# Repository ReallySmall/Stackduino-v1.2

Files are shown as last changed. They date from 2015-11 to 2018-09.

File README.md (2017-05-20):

Stackduino v1.2
==========
Please visit the project site for details: https://www.stackduino.net/boards/v1_2

Copyright 2017 Richard Iles

Permission is hereby granted, free of charge, to any person obtaining a copy of this software and associated documentation files (the "Software"), to deal in the Software without restriction, including without limitation the rights to use, copy, modify, merge, publish, distribute, sublicense, and/or sell copies of the Software, and to permit persons to whom the Software is furnished to do so, subject to the following conditions:

The above copyright notice and this permission notice shall be included in all copies or substantial portions of the Software.

THE SOFTWARE IS PROVIDED "AS IS", WITHOUT WARRANTY OF ANY KIND, EXPRESS OR IMPLIED, INCLUDING BUT NOT LIMITED TO THE WARRANTIES OF MERCHANTABILITY, FITNESS FOR A PARTICULAR PURPOSE AND NONINFRINGEMENT. IN NO EVENT SHALL THE AUTHORS OR COPYRIGHT HOLDERS BE LIABLE FOR ANY CLAIM, DAMAGES OR OTHER LIABILITY, WHETHER IN AN ACTION OF CONTRACT, TORT OR OTHERWISE, ARISING FROM, OUT OF OR IN CONNECTION WITH THE SOFTWARE OR THE USE OR OTHER DEALINGS IN THE SOFTWARE.

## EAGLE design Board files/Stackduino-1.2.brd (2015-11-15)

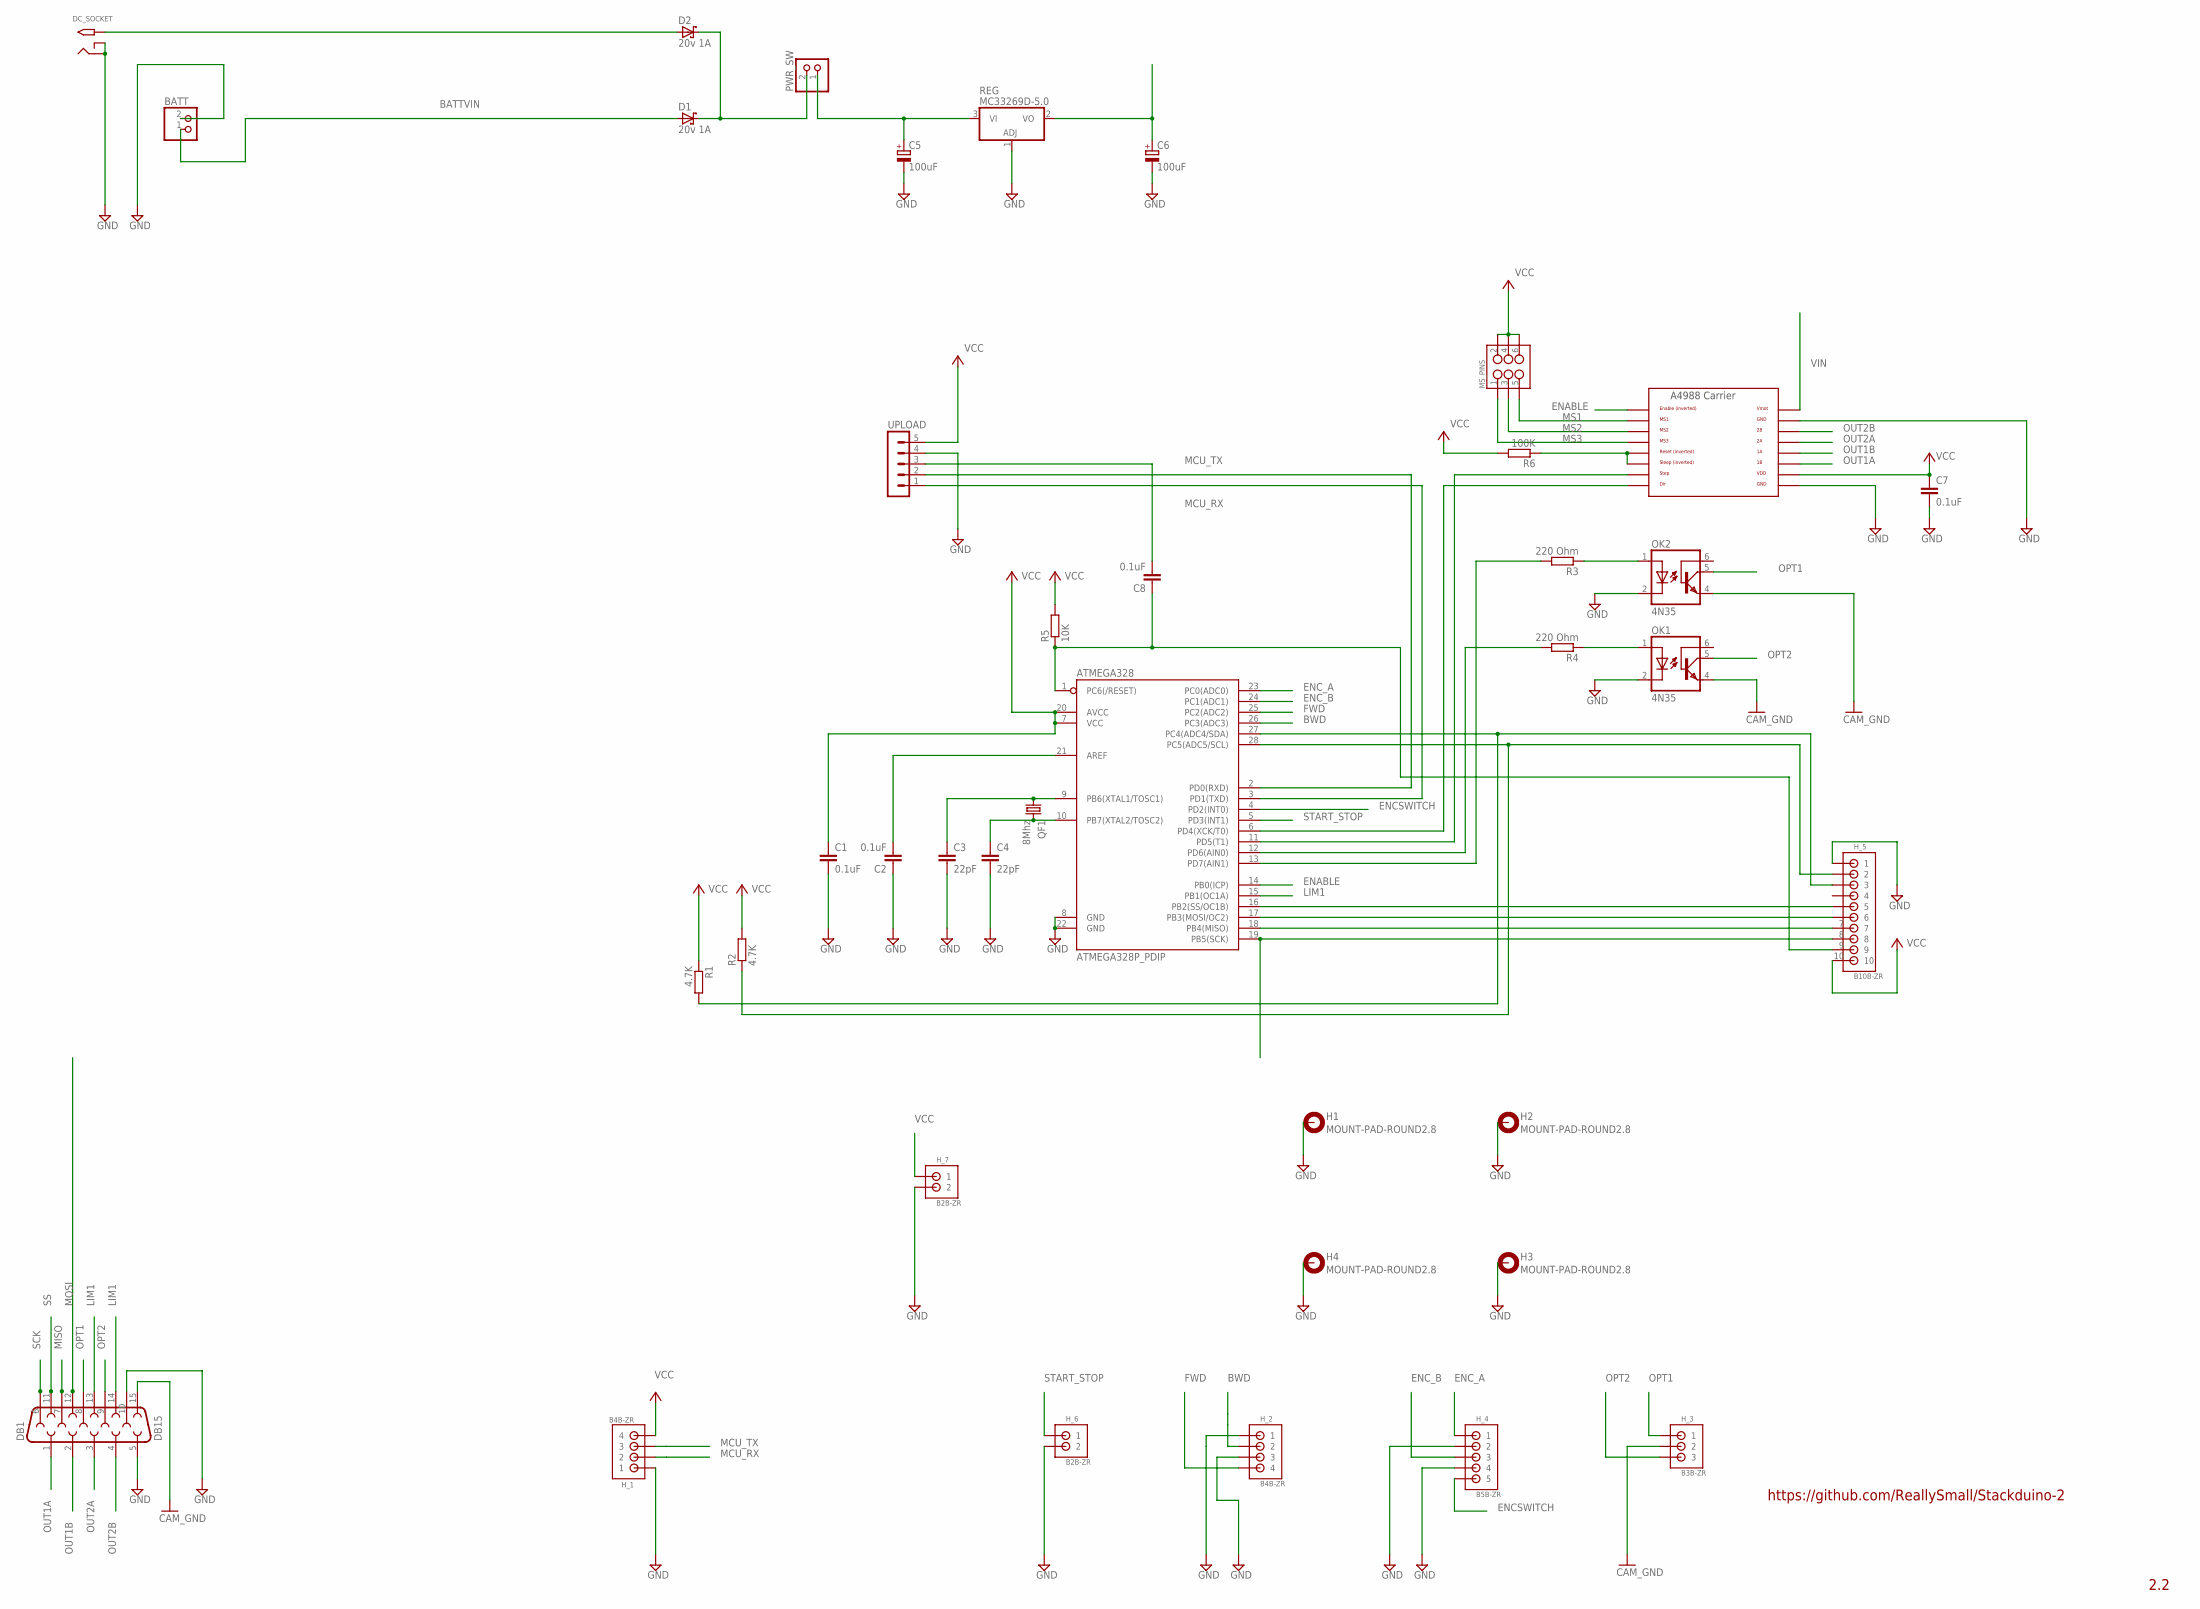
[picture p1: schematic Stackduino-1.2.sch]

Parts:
A4988_CARRIER: A4988BREAKOUT
ATMEGA328: ATMEGA328P_PDIP; DIL28-3
BATT: JST_2PIN-THM; JST-PH-2-THM
C1, C2, C7, C8: 0.1uF; C025-030X050
C3, C4: 22pF; C025-030X050
C5, C6: 100uF; E2,5-7
D1, D2: 20v 1A; DO41-10
DB1: DB15
DC_SOCKET: 2.1MMJACKTHM; PJ-102A
H1, H2, H3, H4: MOUNT-PAD-ROUND2.8; 2,8-PAD
H_1, H_2: B4B-ZR
H_3: B3B-ZR
H_4: B5B-ZR
H_5: B10B-ZR
H_6, H_7: B2B-ZR
MS_PINS: M03X22X3_SILK_MALE_PTH; 2X3
OK1, OK2: 4N35; DIL06
PWR_SW: JST_2PIN-THM; JST-PH-2-THM
QF1: 8Mhz; HC49U-V
R1, R2: 4.7K; 0207/7
R3, R4: 220 Ohm; 0207/7
R5: 10K; 0207/7
R6: 100K; 0207/7
REG: MC33269D-5.0; DPACK
UPLOAD: MA05-1

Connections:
A4988_RESET: A4988_CARRIER.RST, A4988_CARRIER.SLP (SLEEP), R6.1
ACVIN: D2.A, DC_SOCKET.TIP
BATTVIN: BATT.1 (2), D1.A
BWD: ATMEGA328.26 (PC3(ADC3)), H_2.2
CAM_GND: DB1.15, H_3.2, OK1.4 (EMI), OK2.4 (EMI)
DIR: A4988_CARRIER.DIR, ATMEGA328.6 (PD4(XCK/T0))
ENABLE: A4988_CARRIER.EN, ATMEGA328.14 (PB0(ICP))
ENCSWITCH: ATMEGA328.4 (PD2(INT0)), H_4.5
ENC_A: ATMEGA328.23 (PC0(ADC0)), H_4.1
ENC_B: ATMEGA328.24 (PC1(ADC1)), H_4.3
FWD: ATMEGA328.25 (PC2(ADC2)), H_2.4
GND: A4988_CARRIER.GND, A4988_CARRIER.GND@0 (GND), ATMEGA328.8 (GND), ATMEGA328.22 (GND), BATT.2 (1), C1.2, C2.1, C3.2, C4.2, C5.-, C6.-, C7.2, DB1.5, DB1.10, DC_SOCKET.RING, DC_SOCKET.RING_SW, H1.B2,8, H2.B2,8, H3.B2,8, H4.B2,8, H_1.1, H_2.1, H_2.3, H_4.2, H_4.4, H_5.1, H_6.2, H_7.2, OK1.2 (C), OK2.2 (C), REG.1 (ADJ), UPLOAD.4
I2C_SCL: ATMEGA328.28 (PC5(ADC5/SCL)), H_5.2, R2.1
I2C_SDA: ATMEGA328.27 (PC4(ADC4/SDA)), H_5.3, R1.2
LIM1: ATMEGA328.15 (PB1(OC1A)), DB1.13, DB1.14
MCU_RX: ATMEGA328.2 (PD0(RXD)), H_1.2, UPLOAD.2
MCU_TX: ATMEGA328.3 (PD1(TXD)), H_1.3, UPLOAD.1
MISO: ATMEGA328.18 (PB4(MISO)), DB1.7, H_5.7
MOSI: ATMEGA328.17 (PB3(MOSI/OC2)), DB1.12, H_5.6
MS1: A4988_CARRIER.MS1, MS_PINS.5
MS2: A4988_CARRIER.MS2, MS_PINS.3
MS3: A4988_CARRIER.MS3, MS_PINS.1
unnamed: D1.C, D2.C, PWR_SW.2 (1)
unnamed: ATMEGA328.1 (PC6(/RESET)), C8.1, H_5.9, R5.1
unnamed: C8.2, UPLOAD.3
unnamed: ATMEGA328.21 (AREF), C2.2
OPT1: DB1.8, H_3.1, OK2.5 (COL)
OPT1_IN: OK2.1 (A), R3.1
OPT1_MCU: ATMEGA328.13 (PD7(AIN1)), R3.2
OPT2: DB1.9, H_3.3, OK1.5 (COL)
OPT2_IN: OK1.1 (A), R4.1
OPT2_MCU: ATMEGA328.12 (PD6(AIN0)), R4.2
OUT1A: A4988_CARRIER.1B, DB1.1
OUT1B: A4988_CARRIER.1A, DB1.2
OUT2A: A4988_CARRIER.2A, DB1.3
OUT2B: A4988_CARRIER.2B, DB1.4
SCK: ATMEGA328.19 (PB5(SCK)), DB1.6, H_5.8
SS: ATMEGA328.16 (PB2(SS/OC1B)), DB1.11, H_5.5
START_STOP: ATMEGA328.5 (PD3(INT1)), H_6.1
STEP: A4988_CARRIER.STEP, ATMEGA328.11 (PD5(T1))
VCC: A4988_CARRIER.VDD, ATMEGA328.7 (VCC), ATMEGA328.20 (AVCC), C1.1, C6.+, C7.1, H_1.4, H_5.10, H_7.1, MS_PINS.2, MS_PINS.4, MS_PINS.6, R1.1, R2.2, R5.2, R6.2, REG.2 (VO), UPLOAD.5
VIN: A4988_CARRIER.VMOT, C5.+, PWR_SW.1 (2), REG.3 (VI)
XTAL1: ATMEGA328.9 (PB6(XTAL1/TOSC1)), C3.1, QF1.1
XTAL2: ATMEGA328.10 (PB7(XTAL2/TOSC2)), C4.1, QF1.2

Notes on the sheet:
https://github.com/ReallySmall/Stackduino-2
2.2

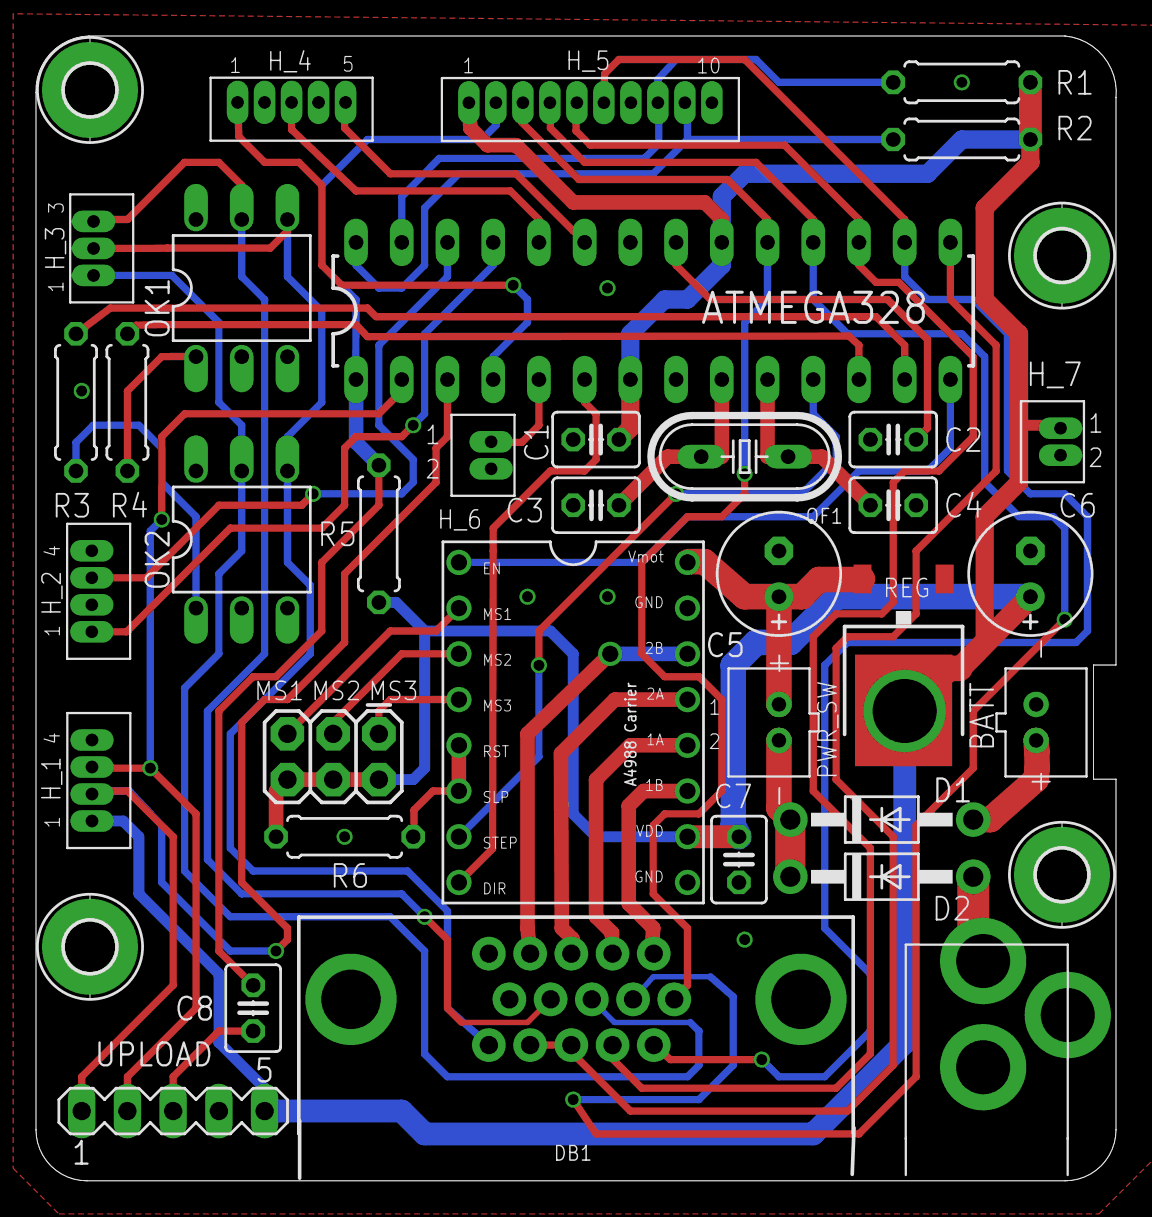
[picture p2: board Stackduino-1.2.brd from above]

Board: 2 copper layers, 60.0 x 63.6 mm, 39 parts (0 on the bottom side), 44 nets.

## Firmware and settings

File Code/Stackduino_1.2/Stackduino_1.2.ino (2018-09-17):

//////////////////////////////////////////////////////////////////////////////////////////////////////////
//  STACKDUINO 1.2 (BETA)                                                                               //
//                                                                                                      //
//  https://github.com/ReallySmall/Stackduino-2                                                         //
//                                                                                                      //
//  An Arduino compatible Focus Stacking Controller                                                     //
//  Richard Iles 2017                                                                                   //
//                                                                                                      //
//  Written for use with the Digole 128 x 64 OLED module using default font (4 rows of 16 chars)        //
//  To support other fonts or screens, some recoding will be required                                   //
////////////////////////////////////////////////////////////////////////////////////////////////////////*/

/* YOUR HARDWARE SETTINGS */
const float HARDWARE_CONSTANT = 0.2; // a number which on your system results in one step of the motor resulting in one micron of movement
const byte MICRO_STEPS = 16; // the microstepping amount set on the stepper driver

/* DEFINES AND DEPENDENCIES (you probably don't need to change these */
#define _Digole_Serial_I2C_ // OLED screen configured with solder jumper to run in I2C mode
#define OLED_ROWS 4 // OLED text rows
#define OLED_COLS 16 // OLED text columns
#define ENC_A A0 // Rotary encoder
#define ENC_B A1 // Rotary encoder
#define ENC_PORT PINC // Rotary encoder
#define settings_elements 4 // Number of properties in each settings

#include "DigoleSerial.h" // https://github.com/chouckz/HVACX10Arduino/blob/master/1.0.1_libraries/DigoleSerial/DigoleSerial.h
#include <Wire.h> //
#include <EEPROM.h>
#include "avr/pgmspace.h"


/* CREATE REQUIRED OBJECTS */
DigoleSerialDisp screen(&Wire, '\x27'); // Digole OLED in i2c mode


typedef struct { // A struct type for storing char arrays
  char title [OLED_COLS + 1];
} stringConstants;

const stringConstants settings_titles[] PROGMEM = { // A struct of char arrays stored in Flash
  {"Stackduino v1.2"},
  {"Slice size"},
  {"Slices"},
  {"Pre-shot pause"},
  {"Post-shot pause"},
  {"Mirror lockup"},
  {"Bracketing"},
  {"Return to home"},
  {"Motor speed"}
};

char uom_chars[3] = {'u', 'm', 'c'};

const int SETTINGS_HOME_SCREEN = 0;
const int SETTINGS_SLICE_SIZE = 1;
const int SETTINGS_NUMBER_OF_SLICES = 2;
const int SETTINGS_PRE_PAUSE_TIME = 3;
const int SETTINGS_POST_PAUSE_TIME = 4;
const int SETTINGS_MIRROR_LOCKUP = 5;
const int SETTINGS_BRACKETING = 6;
const int SETTINGS_RETURN_TO_START = 7;
const int SETTINGS_STEPPER_SPEED = 8;

struct SettingsDesc { // A struct type for storing settings

  byte lower; // The lowest value the setting may have
  long int upper; // The highest value the setting may have
  byte multiplier; // Any multiplier to apply when the setting is incremented
  byte numberOfSubmenus;

} settingsDesc[] = { // A struct of user menu settings
  {}, // The home screen - not actually used by any functions at the moment, but the placeholder array must exist to maintain the correct indexing
  {1, 150000, 1, 3}, // "Slice size"
  {5, 500, 5, 0}, // "Number of slices"
  {0, 60, 1, 0}, // "Pre-pause time"
  {1, 60, 1, 0}, // "Post-pause time"
  {0, 1, 1, 0}, // "Mirror lockup"
  {1, 10, 1, 0}, // "Bracketing"
  {0, 1, 1, 0}, // "Return to start"
  {5, 20, 1, 0} // "Stepper speed"
};

long int settingsValue[] = {
  0,
  1,
  5,
  2,
  1,
  0,
  1,
  0,
  1
};

byte settings_count = sizeof(settingsDesc) / sizeof(SettingsDesc); // The number of settings
char char_buffer[OLED_COLS + 1]; // make sure this is large enough for the largest string it must hold



/* SET UP REMAINING ATMEGA PINS */
const byte main_button = 3;  //start/ stop stack button
const byte encoder_button = 2; //select/ unselect menu item button
const byte step_dir = 4; // Direction pin on A4988 stepper driver
const byte do_step = 5; // Step pin on A4988 stepper driver
const byte cam_focus = 6; // Camera autofocus signal
const byte cam_shutter = 7; // Camera shutter signal
const byte stepper_enable = 8; // Enable/ disable the stepper driver
const byte btn_bwd = A2; // Manual forward button
const byte btn_fwd = A3; // Manual backward button
const byte limit_switch = 9;


/* SETTINGS */
const int uom_multipliers[] = {1, 1000, 10000}; // Multipliers for active unit of measure (mn, mm or cm)

boolean app_connected = false; // Whether a remote application is actively communicating with the controller
boolean can_disable_stepper = true; // Whether to disable the A4988 stepper driver when possible to save power and heat
boolean update_display = true; // True whenever functions are called which change a setting's value
boolean update_header = true; // True whenever the value of an item in the header changes
boolean home_screen = true;
boolean previous_direction;

long int menu_item = 0; // The active menu item
int submenu_item = 0; // Submenu item, if any
int increments = 0; // Count increments the active menu setting should be changed by on the next poll
byte slice_count = 0; // Count of number of focus slices made so far in the stack

//main button toggle
volatile int main_button_state = LOW; //the current state of the output pin
volatile int main_button_reading; //the current reading from the input pin
volatile int main_button_previous = HIGH; //the previous reading from the input pin
volatile long main_button_time = 0; //the last time the output pin was toggled
volatile long main_button_debounce = 400; //the debounce time, increase if the output flickers

//rotary pushButton toggle
volatile int rotary_button_state = HIGH; //the current state of the output pin
volatile int rbreading; //the current reading from the input pin
volatile int rbprevious = LOW; //the previous reading from the input pin
volatile long rbtime = 0; //the last time the output pin was toggled
volatile long rbdebounce = 400; //the debounce time, increase if the output flickers

unsigned long time_stack_started;

char* app_conn_icon = "";

volatile byte btn_reading; // The current reading from the button
volatile byte btn_previous = LOW; // The previous reading from the button
volatile long btn_time = 0; // The last time the button was toggled

const byte SETTINGS_VERSION = 3;

void loadSettings(){
  byte value = EEPROM.read(0);
  if (value != SETTINGS_VERSION) return;

  EEPROM.get(1, settingsValue);
}

void saveSettings(){
  EEPROM.put(1, settingsValue);
  EEPROM.update(0, SETTINGS_VERSION);
}


/* SETUP() */
void setup() {

  /* SET ATMEGA PINMODES AND PULLUPS */
  pinMode(encoder_button, INPUT); digitalWrite(encoder_button, HIGH);
  pinMode(main_button, INPUT); digitalWrite(main_button, HIGH);
  pinMode(ENC_A, INPUT); digitalWrite(ENC_A, HIGH);
  pinMode(ENC_B, INPUT); digitalWrite(ENC_B, HIGH);
  pinMode(limit_switch, INPUT); digitalWrite(limit_switch, HIGH);

  pinMode(step_dir, OUTPUT); digitalWrite(step_dir, HIGH);
  pinMode(do_step, OUTPUT); digitalWrite(do_step, LOW);
  pinMode(cam_focus, OUTPUT); digitalWrite(cam_focus, LOW);
  pinMode(cam_shutter, OUTPUT); digitalWrite(cam_shutter, LOW);
  pinMode(btn_fwd, OUTPUT); digitalWrite(btn_fwd, HIGH);
  pinMode(btn_bwd, OUTPUT); digitalWrite(btn_bwd, HIGH);

  /* SET UP INTERRUPTS */
  attachInterrupt(1, button_main_change, CHANGE);  //main button on interrupt 1
  attachInterrupt(0, button_rotary_change, CHANGE);  //encoder button on interrupt 0

  pciSetup(ENC_A); // ATMega pin change interrupt
  pciSetup(ENC_B); // ATMega pin change interrupt

  Wire.begin(); // join i2c bus
  Serial.begin(9600); // Start serial (always initialise at 9600 for compatibility with OLED)

  loadSettings();
}



/*////////////////////////////////////////////////////////////////////////////////////////////////////////
// FUNCTIONS                                                                                            //
////////////////////////////////////////////////////////////////////////////////////////////////////////*/



/* UPDATE THE SCREEN WHEN DATA CHANGES
*
* Clears the screen then re-outputs it
*
*/
void screenUpdate() { /* WIPE THE SCREEN, PRINT THE HEADER AND SET THE CURSOR POSITION */

  screen.clearScreen(); // Repaints the screen blank
  screen.drawBox(1, 17, 128, 1); // Draw a horizontal line to mark out the header section
  screen.setPrintPos(0, 2); // Set text position to beginning of content area

}



/* PRINT TEXT ON DIGOLE OLED SCREEN
*
* Assumes the default font is in use (allowing 4 rows of 16 characters)
*
* char_length => The length of the string in the char buffer
* text => The string to be centered and printed
* print_pos_y => The text line to print on
*
*/
void screenPrint(byte char_length, char* text, byte print_pos_y = 4) {

  // Calculate the start point on x axis for the number of characters in the string to print it centrally
  byte print_pos_x = (OLED_COLS - char_length) / 2;

  screen.setPrintPos(print_pos_x, print_pos_y); // Set the start point for printing

  byte offset_x = char_length % 2 != 0 ? 4 : 0; // If the string to print is an odd number in length, apply an offset to centralise it
  byte offset_y = print_pos_y == 4 ? -2 : 0; // If printing on line 4, nudge upwards a bit to prevent lower parts of characters like 'g' being cut off

  screen.setTextPosOffset(offset_x, offset_y); // Set the required positioning offsets defined above

  screen.print(text); // Finally, print the centered text to the screen

}



/* ENABLE OR DISABLE THE STEPPER DRIVER AND SET DIRECTION
*
* enable => Enables the stepper driver if true, Disables if false and option set
* direction => Set as 0 for forward direction, 1 for backward direction
* toggle_direction => Toggle the direction to be the opposite of its current state
*
*/
void stepperDriverEnable(boolean enable = true, byte direction = 0, boolean toggle_direction = false) {

  if (enable) {
    digitalWrite(stepper_enable, LOW); // Enable the stepper driver

    if (toggle_direction) { // Toggle the direction to set (used by limit switches)
      direction = !previous_direction;
    }

    digitalWrite(step_dir, !direction); // Set the direction
    previous_direction = direction; // Set the new direction for future toggle_direction calls

  }
  else {
    digitalWrite(stepper_enable, HIGH); // Disable the stepper driver
  }


}



/* MOVE STAGE FORWARD BY ONE SLICE */
void stepperMoveOneSlice(byte direction = 1){

  int slice_size = settingsValue[SETTINGS_SLICE_SIZE];
  float hardware = HARDWARE_CONSTANT;
  int unit_of_measure = 1;
  byte micro_steps = MICRO_STEPS;

  unsigned int rounded_steps = (slice_size * hardware * micro_steps * unit_of_measure) + 0.5;
  Serial.println(rounded_steps);
  Serial.println(direction);

  stepperDriverEnable(true, direction, false); // Enable the stepper driver


  for (unsigned int i = 0; i < rounded_steps; i++) { // Move the required number of steps
    stepperDriverStep(); // Send a step signal to the stepper driver
    if (!stepperDriverInBounds() || stackCancelled()) break; // Exit early if the stack has been cancelled or a limit switch is hit

  }

  stepperDriverEnable(false); // Disable the stepper driver

}


/* MOVE STAGE BACKWARD AND FORWARD */
void stepperDriverManualControl(byte direction = 1, boolean serial_control = false, boolean short_press = false) {

    if ((digitalRead(btn_fwd) == LOW || digitalRead(btn_bwd) == LOW || serial_control == true) && stepperDriverInBounds()) {

      unsigned long button_down = millis();
      char* manual_ctl_strings[2] = {"<", ">"};

      screenUpdate();
      screenPrint(sprintf_P(char_buffer, PSTR("Moving stage")), char_buffer, 2);
      screen.setPrintPos(4, 4);
      for (byte i = 0; i < 8; i++) {
        screen.print(manual_ctl_strings[direction]);
      }

      stepperDriverEnable(true, direction); // Enable the stepper driver and set the direction

      // Move the stage for as long as the control button is pressed
      while (stepperDriverInBounds() && Serial.available() == 0 && (digitalRead(btn_fwd) == LOW || digitalRead(btn_bwd) == LOW)) {


          stepperDriverStep();
          if (!stepperDriverInBounds()) stepperDriverClearLimitSwitch();

       }

    stepperDriverEnable(false); // Disable the stepper driver
    update_display = true; // Go back to displaying the active menu item once manual control button is no longer pressed

    }

}



/* APPLICATION CONNECTION STATUS
*
* NOT CURRENTLY USED
*
* Sends a keep-alive token and expects one back the next time it is called
* Otherwise assumes the connection with the remote application has been lost
* Also sets the icon for current connection status
*
*/
void appConnection() {

  static boolean last_app_conn_stat;

  if (app_connected != last_app_conn_stat) {
    update_display = true;
  }

  last_app_conn_stat = app_connected;

}

void pauseStack(byte pauseTime) {
  for (byte i = 0; i < pauseTime; i++) { // Count down the pause for camera on the screen
    screenPrintPositionInStack();
    screenPrint(sprintf_P(char_buffer, PSTR("Resume in %ds"), pauseTime - i), char_buffer, 4);
    pause(1000);

    if (stackCancelled()) break; // Exit early if the stack has been cancelled
  }
}

/* SIGNAL CAMERA TO TAKE IMAGE(S)
*
* Optionally sends multiple delay seperated signals for exposure bracketing each focus slice
*
*/
void captureImages() {

  screenUpdate();

  for (byte i = 1; i <= settingsValue[SETTINGS_BRACKETING]; i++) { // Number of brackets to take per focus slice

    screenPrintPositionInStack();

    if (settingsValue[SETTINGS_BRACKETING] > 1) { // If more than one image is being taken, display the current position in the bracket
      screenPrint(sprintf_P(char_buffer, PSTR("Bracket %d/%ld"), i, settingsValue[SETTINGS_BRACKETING]), char_buffer, 4);
    }

    pauseStack(settingsValue[SETTINGS_PRE_PAUSE_TIME]);
    if (stackCancelled()) break;
    shutter(); // Take the image
    pauseStack(settingsValue[SETTINGS_POST_PAUSE_TIME]);

    if (stackCancelled()) break; // Exit early if the stack has been cancelled
  }

  update_display = true;
}



/* TRIGGER THE CAMERA SHUTTER
*
* Optionally sends two delay seperated signals to support mirror lockup
*
*/
void shutter() {

  for (byte i = 0; i <= settingsValue[SETTINGS_MIRROR_LOCKUP]; i++) {

    screenPrintPositionInStack();

    if (settingsValue[SETTINGS_MIRROR_LOCKUP] && i == 0) { // If mirror lockup enabled
      screenPrint(sprintf_P(char_buffer, PSTR("Mirror up")), char_buffer, 4);
    } else {
      screenPrint(sprintf_P(char_buffer, PSTR("Shutter")), char_buffer, 4);
    }

    pause(300);

    digitalWrite(cam_focus, HIGH); // Trigger camera autofocus - camera may not take picture in some modes if this is not triggered first
    digitalWrite(cam_shutter, HIGH); // Trigger camera shutter

    pause(200); //Small delay needed for camera to process above signals

    digitalWrite(cam_shutter, LOW); // Switch off camera trigger signal
    digitalWrite(cam_focus, LOW); // Switch off camera focus signal

    if (settingsValue[SETTINGS_MIRROR_LOCKUP] && i == 0) { // If mirror lockup enabled
      pause(2000); // Pause between mirror up and shutter actuation
    }
  }
}



/*////////////////////////////////////////////////////////////////////////////////////////////////////////
//  BUTTON FUNCTIONS                                                                                    //
////////////////////////////////////////////////////////////////////////////////////////////////////////*/

void button_main_change(){ /* RETURN CURRENT STATE OF MAIN PUSH BUTTON */

  main_button_reading = digitalRead(main_button);

  if (main_button_reading == LOW && main_button_previous == HIGH && millis() - main_button_time > main_button_debounce) {
    if (main_button_state == HIGH)
    main_button_state = LOW;
    else
    main_button_state = HIGH;

    main_button_time = millis();
  }

  main_button_previous = main_button_reading;
}

void button_rotary_change(){/* RETURN CURRENT STATE OF ROTARY ENCODER'S PUSH BUTTON */

  rbreading = digitalRead(encoder_button);
  if (rbreading == LOW && rbprevious == HIGH && millis() - rbtime > rbdebounce) {
    if (rotary_button_state == HIGH && menu_item != 0)
    {
        submenu_item = 0;
        rotary_button_state = LOW;
    }
      else
    {
      if (settingsDesc[menu_item].numberOfSubmenus)
      {
        submenu_item++;

        if (submenu_item >= settingsDesc[menu_item].numberOfSubmenus)
          rotary_button_state = HIGH;
      }
      else
      {
        rotary_button_state = HIGH;
      }
    }
    rbtime = millis();
  }

  update_display = true;
  rbprevious = rbreading;

}




void startStack() {

  main_button_state = main_button_state == HIGH ? LOW : HIGH;

}

// This is designed to flag a running stack as cancelled
// It's set with an interrupt with an emphasis on speed of execution
// So there's no debouncing or toggling of state
void cancelStack(){

  if(main_button_state){
    main_button_state = LOW;
  }

}

void menuNav() {

  if (menu_item != 0) {
    rotary_button_state = rotary_button_state == true ? false : true;
  }

  update_display = true;

}



/* RETURN ANY CHANGE IN ROTARY ENCODER POSITION
*
* Using work by:
* http://www.circuitsathome.com/mcu/rotary-encoder-interrupt-service-routine-for-avr-micros
*
*/
int8_t encoderRead() {

  static int8_t enc_states[] = {
    //0,-1,1,0,1,0,0,-1,-1,0,0,1,0,1,-1,0 // Use this line instead to increment encoder in the opposite direction
    0, 1, -1, 0, -1, 0, 0, 1, 1, 0, 0, -1, 0, -1, 1, 0
  };

  static uint8_t old_AB = 0;

  old_AB <<= 2; // Remember previous state
  old_AB |= ( ENC_PORT & 0x03 ); // Add current state

  int8_t encoder_data = ( enc_states[( 0x0f & old_AB )]);

  static int8_t encoder_pulse_counter = 0; // Counts pulses from encoder

  if (encoder_data) { // If Gray Code returns a valid input (1 or -1)
    encoder_data == 1 ? encoder_pulse_counter++ : encoder_pulse_counter--;
  }

  if (encoder_pulse_counter > 3) { // Record the encoder was moved by one click (detent)
    increments++;
    encoder_pulse_counter = 0;
  }

  else if (encoder_pulse_counter < -3) { // Record the encoder was moved by one click (detent) in the opposite direction
    increments--;
    encoder_pulse_counter = 0;
  }

}



/* SET UP ATMEGA PIN CHANGE INTERRUPTS */
void pciSetup(byte pin)
{
  *digitalPinToPCMSK(pin) |= bit (digitalPinToPCMSKbit(pin));  // enable pin
  PCIFR  |= bit (digitalPinToPCICRbit(pin)); // clear any outstanding interrupt
  PCICR  |= bit (digitalPinToPCICRbit(pin)); // enable interrupt for the group
}



/* READ THE ENCODER ON ANALOGUE PORT INTERRUPT */
ISR (PCINT1_vect) {

  encoderRead();

}



/* PAUSE
*
* Delays are needed throughout the code, but these should be non-blocking
*
*/
void pause(unsigned int length) {

  unsigned long initial_millis = millis(); // Get the current millis
  unsigned long end_millis = initial_millis + length; // Define when the pause ends

  while (end_millis > millis()) { // If the end of the pause time hasn't yet been reached

    if (stackCancelled()) break; // Check continuously for any reason to end it early

  }

}
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
void loop() {


  /* MENUS AND STAGE CONTROL
  *
  * Manual control of linear stage is only enabled when in this section of the loop
  * - prevents running stacks being ruined by accidental button presses
  *
  * Menu navigation controlled either by rotary encoder with integral push button, or via serial
  *
  */
  if (main_button_state == LOW) { // User settings menus and manual stage control

    btnPress(main_button);
    btnPress(btn_fwd);
    btnPress(btn_bwd);
    serialCommunications();  // Check for commands via serial
    menuInteractions(); // Change menu options and update the screen when changed
  }



  /* FOCUS STACK
  *
  * Images are captured, the stage is advanced and the process is repeated for as many times as needed
  *
  */
  else {

    byte slice_size = settingsValue[SETTINGS_SLICE_SIZE];
    byte slices = settingsValue[SETTINGS_NUMBER_OF_SLICES];

    saveSettings();

    time_stack_started = millis();

    slice_count = 1; // Register the first image(s) of the stack is being taken
    screenPrintPositionInStack(); // Print the current position in the stack
    captureImages(); // Take the image(s) for the first slice of the stack

    for (unsigned int i = 1; i < slices; i++) { // For each subsequent focus slice in the stack

      slice_count++; // Record slices made in the stack so far

      if (stackCancelled()) break; // Exit early if the stack has been cancelled

      screenPrintPositionInStack(); // Print the current position in the stack
      // Print that the stage is being advanced by x units
      screenPrint(sprintf_P(char_buffer, PSTR("Advance %d"), slice_size), char_buffer, 4);

      if (stackCancelled()) break; // Exit early if the stack has been cancelled

      stepperDriverEnable(true, 1); // Enable the stepper driver and set the direction to forwards
      stepperMoveOneSlice(1); // Move forward by one focus slice

      if (!stepperDriverInBounds()) stepperDriverClearLimitSwitch(); // Clear hit limit switch
      if (stackCancelled()) break; // Exit early if the stack has been cancelled

      stepperDriverEnable(false); // Disable the stepper driver
      captureImages(); // Take image(s)

    }

    stackEnd(); // End of focus stack tasks

  }
}

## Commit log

2017-01-08 Folder tidyup
    [Stackduino-1.2.brd, Stackduino-1.2.sch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]
2017-05-20 fixed return to start function
    [Stackduino_1.2.ino]
2018-09-16 Initial changes
    Added saving settings to EEPROM.
    Added/fixed limit switches support.
    Fixed settings menu.
    Moved pause after rail move and before shutter is triggered.
    [Stackduino_1.2.ino]

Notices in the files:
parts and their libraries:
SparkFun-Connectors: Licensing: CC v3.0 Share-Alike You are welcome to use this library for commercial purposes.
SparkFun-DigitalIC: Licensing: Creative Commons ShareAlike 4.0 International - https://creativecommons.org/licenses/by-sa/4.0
